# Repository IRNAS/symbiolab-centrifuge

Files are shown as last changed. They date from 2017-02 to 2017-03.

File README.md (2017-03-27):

# Symbiolab centrifuge

## Overview	
Symbiolab centrifuge is a DIY project still in development for Symbiolab at institute IRNAS. The centrifuge is based on our very own Symbiolab driver PCB on which a repository will be created in a short future. The whole centrifuge, besides the PCB, is made of cheap and easy accsesible parts, like brushless motors, and lasercut or 3D printed parts.

## Table of contents
 - [overview](#OvER)
 - [Part list](#LIST)
 - [Parts](#PARTS)
 - [Centrifuge schematic](#SCH)
 - [Centrifuge housing](#DXF)
 - [arduino code](#CODE)

## Required parts list	
 - Symbiolab driver
 - Brushless motor 
 - Electronic speed contoller "ESC"
 - IR tachometer
  * LMV 761
  * IR LED
  * IR photodiode
  * 33K resistor
  * 25 ohm resistor
 - Three state switch
 - DC-025 DC power jack connector
 - XT60 female connector
 - Electric cables and jumper wires
 - Acrylic glass "plexiglas"
 - M3 15mm nuts and bolts

## Parts	

### Symbiolab driver
Symbiolab driver is a project developed by Institute IRNAS, for DIY laboratory equipment. this is its first finished installment. Symbiolab driver is based on [NODEMCU](http://www.nodemcu.com/index_en.html) firmware, that enables future expansion to wireless controll.

### Brushless motor/ ESC
For the Symbiolab centrifuge we are using a [A2212 KV1000](http://www.robotdigg.com/product/710/A2212-brushless-drone-motor) brushless motor controlled by a [Skywalker 40A ESC controller](http://www.robotdigg.com/product/802/Skywalker-40A-ESC)

### IR tachometer
IR tachometer is used for RPM sensing and is crucial to achieving a self speed regulating controll. The sensor works with the help of reflecting light from the brushless motor therefore it is important to tape up a part of the motor, with a black(dark) tape, to create different levels of light reflecting from the motor. A LMV 761 comparator is added to transform the analog value from the photodiode to a rectangle pulse when it exceeds a reference value set via potentiometer. With this it is possible to connect the photodiode to a interrupt pin, making shure we do not miss out any positive pulses resoulting a foulty rpm reading. this method is also fater than ADC reading, thus making the whole controller faster.

#### Tachometer schematic 
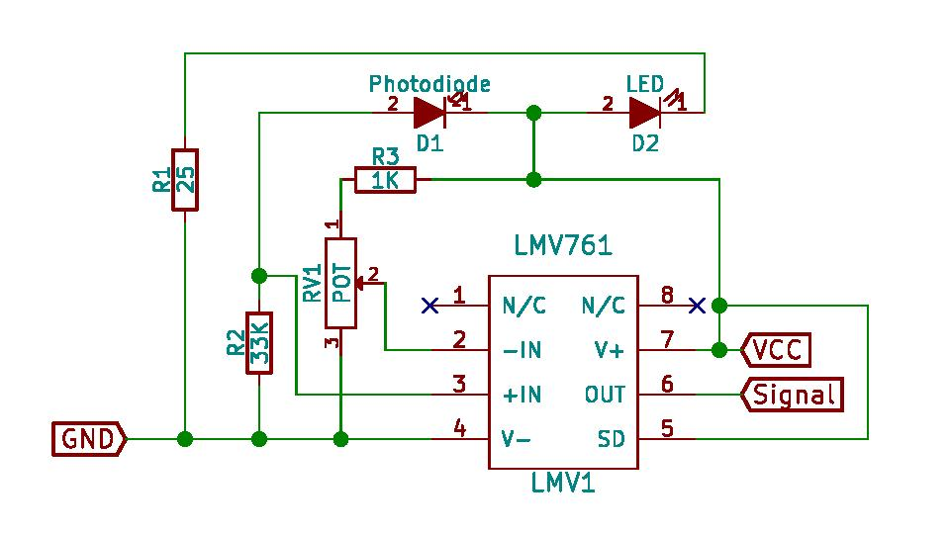
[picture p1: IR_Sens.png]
Tachometer schematic


### Three state switch
the switch is essentially used to turn on/off the centrifuge, however you can switch between power from the DC jack or LiPo battery.

## Centrifuge schematic	
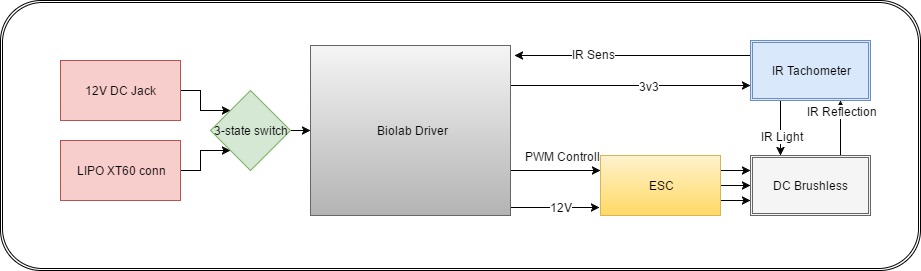
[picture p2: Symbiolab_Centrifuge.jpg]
Centrifuge schematic

To choose the power supply source, both the dc jack and XT60 are connected the 3 state switch on pins IN1 and IN2. The switch output is connected to the 12V IN terminal block on the Biolab driver. For IR tachomer we need to cennect 3v3 power suply from the Biolab driver, in return the IR tachomer sends back IR Sens data(HIGH or LOW) depending on the motor position.  The ESC is connnected to the Biolab driver via 12v power supply and the PWM GPIO.

The default pins on the Biolab drivers are:

FUNCTION|PIN NO.
--------|-------
ESC PWM | D0
IR Sens | D8

Or you could also change the pin definitions in the [Code](https://github.com/Ubercic/Symbiolab_Centrifuge/blob/ArduinoCode/ArduinoCode/CentrifugaV1RPM_No_PID/CentrifugaV1RPM_No_PID.ino)

## Centrifuge housing	
All the components for the housing are lasercut from plexiglas (approx 500mm x500mm) and screwed together with M3 15mm nuts and bolts. The DXF files can be found in the [DXF_Files](https://github.com/Ubercic/Symbiolab_Centrifuge/tree/master/DXF_Files) folder.

## Arduino code	
The code is developed in the Arduino IDE environment using [Arduino core](https://github.com/esp8266/Arduino) for use of the lua based NODEMCU with the ease of arduino coding. A working arduino code is uploaded, but it still needs some fine tuning and testing.

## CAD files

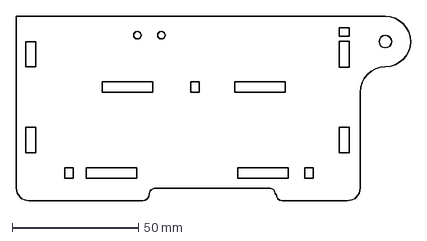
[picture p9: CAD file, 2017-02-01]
DXF_Files/BASE_RIGHT.dxf
156.0 x 73.0 mm

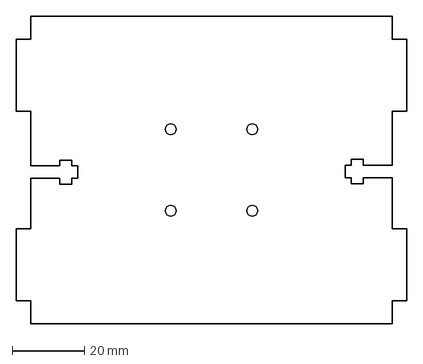
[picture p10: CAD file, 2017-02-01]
DXF_Files/MOTOR_BASE.dxf
108.0 x 85.0 mm

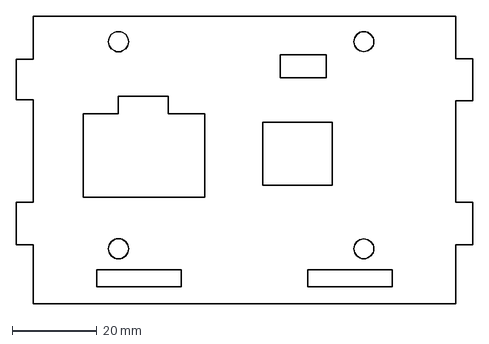
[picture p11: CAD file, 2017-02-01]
DXF_Files/BASE_FRONT.dxf
108.0 x 68.0 mm

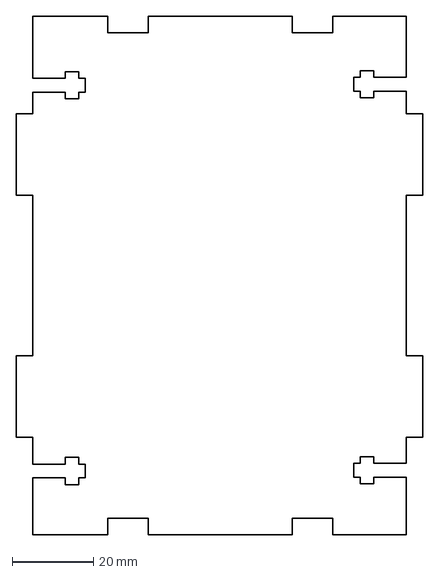
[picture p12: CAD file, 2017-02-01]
DXF_Files/COVER_TOP.dxf
100.0 x 127.6 mm

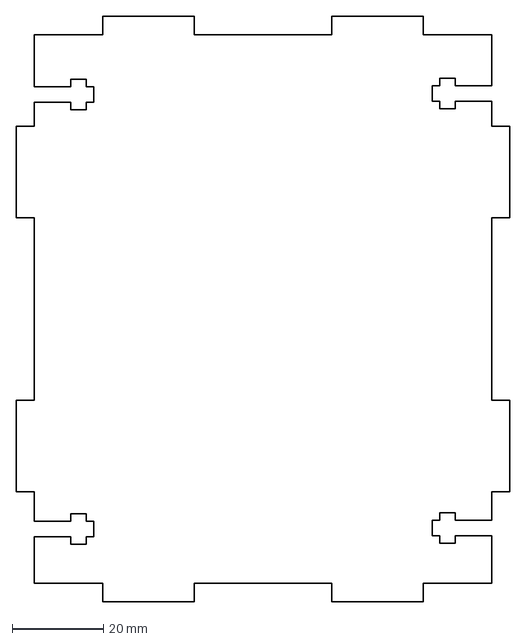
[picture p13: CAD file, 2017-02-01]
DXF_Files/BASE_BOTTOM.dxf
108.0 x 128.0 mm

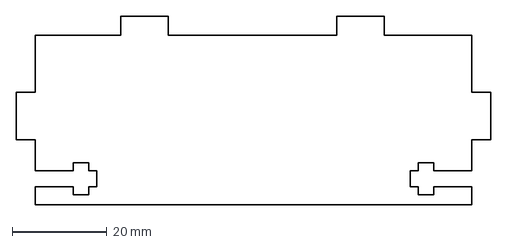
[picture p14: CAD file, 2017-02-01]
DXF_Files/COVER_BACK.dxf
100.0 x 39.8 mm

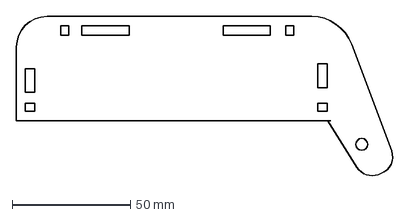
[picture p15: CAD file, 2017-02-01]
DXF_Files/COVER_LEFT.dxf
160.0 x 68.0 mm

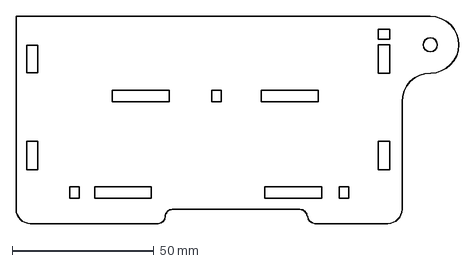
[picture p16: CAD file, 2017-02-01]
DXF_Files/BASE_LEFT.dxf
156.0 x 73.0 mm

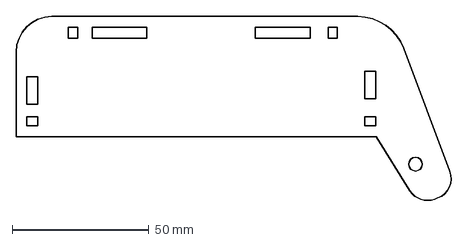
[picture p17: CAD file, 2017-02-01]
DXF_Files/COVER_RIGHT.dxf
159.3 x 68.0 mm

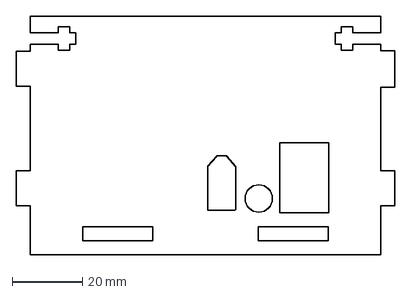
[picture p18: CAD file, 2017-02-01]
DXF_Files/BASE_BACK.dxf
108.0 x 68.0 mm

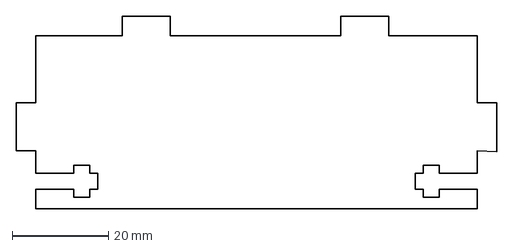
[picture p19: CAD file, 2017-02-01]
DXF_Files/COVER_FRONT.dxf
100.0 x 40.0 mm

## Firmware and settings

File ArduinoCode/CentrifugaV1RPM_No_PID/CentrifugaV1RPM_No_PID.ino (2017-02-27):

/**The MIT License (MIT)

Copyright (c) 2015 by Daniel Eichhorn

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
See more at http://blog.squix.ch
*/

#include <Wire.h>
#include <SPI.h>
#include "SSD1306.h"
#include "OLEDDisplayUi.h"
#include <Servo.h> 

SSD1306  display(0x3c, D4, D3);
OLEDDisplayUi ui     ( &display );

// how many frames are there?
int frameCount = 3,overlaysCount = 1;

Servo myservo;

/////////////////////////////////////////////////////// 
//pin definitions
int ESCpin = D0;
int Apin = D6;
int Bpin = D5;
int ENTERpin = D7;
int IRpin = D8;

////////////////////////////////////////////////////////
//ENCODER
int encDIR = 0;
int encSTATE = 0;
int encCOUNT = 0;
volatile byte A_SIG = LOW;
volatile byte B_SIG = HIGH;
volatile byte ENTER = LOW;

////////////////////////////////////////////////////////
// rpm reading 
int sensorvalue;
int state1 = HIGH;
int state2 = LOW;
float RPM = 0;
float TRPM = 0;

///////////////////////////////////////////////////////
//TIMERS
int MIN = 0;
int SEC = 1;
int ESC_PWM = 20;
unsigned long previusMillis = 0;
unsigned long previusSec = 0;
unsigned long TIME = 0;
unsigned long prevMillis = 0;
unsigned long previusPWM = 0;
unsigned long previusENTER = 0;
unsigned long previusPrint = 0;
unsigned long interval = 200;
unsigned long currentTime;
unsigned long prevTime = 0;
unsigned long diffTime = 0;

///////////////////////////////////////////////////////////////////////////////////////////////////
// interrupts for encoder reading
void A_RISE()
{
 detachInterrupt(Apin);
  A_SIG = HIGH;
  if(B_SIG == LOW) encDIR = 1;
  if(B_SIG == HIGH) encDIR = -1;
  ENC_COUNT();
 attachInterrupt(Apin, A_FALL, FALLING);
}
void A_FALL()
{
  detachInterrupt(Apin);
  A_SIG = LOW;
  if(B_SIG == HIGH) encDIR = 1;
  if(B_SIG == LOW) encDIR = -1;
  ENC_COUNT();
  attachInterrupt(Apin, A_RISE, RISING); 
}
void B_RISE()
{
  detachInterrupt(Bpin);
  B_SIG = HIGH;
  if(A_SIG == HIGH) encDIR = 1;
  if(A_SIG == LOW) encDIR = -1;
  ENC_COUNT();
  attachInterrupt(Bpin, B_FALL, FALLING);
}
void B_FALL()
{
  detachInterrupt(Bpin);
  B_SIG = LOW;
  if(A_SIG == LOW) encDIR = 1;
  if(A_SIG == HIGH) encDIR = -1;
  ENC_COUNT();
  attachInterrupt(Bpin, B_RISE, RISING); 
}
///////////////////////////////////////////////////////////////////////////////////////////////////
// interrupts for RPM Sens
void IR_RISE()
{
 detachInterrupt(IRpin);
 state1 = HIGH;
 RPM_Calculator();
 attachInterrupt(IRpin, IR_FALL, FALLING);
}
void IR_FALL()
{
  detachInterrupt(IRpin);
  state1 = LOW;
  RPM_Calculator(); 
  attachInterrupt(IRpin, IR_RISE, RISING); 
}

//////////////////////////////////////////////////////////////////////////////////////////////////
// definiton of frames
void msOverlay(OLEDDisplay *display, OLEDDisplayUiState* state) 
{
  display->setTextAlignment(TEXT_ALIGN_RIGHT);
  display->setFont(ArialMT_Plain_10);
  display->drawString(128, 0, String(millis()));
}

void drawTIME(OLEDDisplay *display, OLEDDisplayUiState* state, int16_t x, int16_t y) 
{
  //basic menu for setting time
  display->setTextAlignment(TEXT_ALIGN_CENTER);
  display->setFont(ArialMT_Plain_16);
  display->drawString(64 , 0 , "SET TIME");
  //display->setTextAlignment(TEXT_ALIGN_LEFT);
  //display->setFont(ArialMT_Plain_10);
  //display->drawString(0 , 20 , "SET TIME");
  display->setFont(ArialMT_Plain_24);
  display->setTextAlignment(TEXT_ALIGN_CENTER);
  String Time = String(MIN) + ":" + String(SEC);
  display->drawString(64 , 28 , Time);
  display->setFont(ArialMT_Plain_10);
  display->setTextAlignment(TEXT_ALIGN_LEFT);
  display->drawString(0 , 52 , "PLUS");
  display->setTextAlignment(TEXT_ALIGN_CENTER);
  display->drawString(64 , 52 , "MINUS");
  display->setTextAlignment(TEXT_ALIGN_RIGHT);
  display->drawString(128 , 52 , "OK");
}

void drawSPEED(OLEDDisplay *display, OLEDDisplayUiState* state, int16_t x, int16_t y) 
{
  // Display to set Rpm
  display->setTextAlignment(TEXT_ALIGN_CENTER);
  display->setFont(ArialMT_Plain_16);
  display->drawString(64 , 0 , "SET SPEED");
  //display->setTextAlignment(TEXT_ALIGN_LEFT);
  //display->setFont(ArialMT_Plain_10);
  //display->drawString(0 , 20 , "SET SPEED");
  display->setFont(ArialMT_Plain_24);
  display->setTextAlignment(TEXT_ALIGN_CENTER);
  String Rpm = String(ESC_PWM);
  display->drawString(64 , 28 , Rpm);
  display->setFont(ArialMT_Plain_10);
  display->setTextAlignment(TEXT_ALIGN_LEFT);
  display->drawString(0 , 52 , "PLUS");
  display->setTextAlignment(TEXT_ALIGN_CENTER);
  display->drawString(64 , 52 , "MINUS");
  display->setTextAlignment(TEXT_ALIGN_RIGHT);
  display->drawString(128 , 52 , "OK");
}

void drawWORK(OLEDDisplay *display, OLEDDisplayUiState* state, int16_t x, int16_t y) 
{

  display->setTextAlignment(TEXT_ALIGN_CENTER);
  display->setFont(ArialMT_Plain_16);
  display->drawString(64 , 0 , "WORKING");
  display->setTextAlignment(TEXT_ALIGN_LEFT);
  display->setFont(ArialMT_Plain_10);
  String RPm = String(RPM) + " rpm";
  display->drawString(0 , 20 , RPm);
  display->setFont(ArialMT_Plain_24);
  display->setTextAlignment(TEXT_ALIGN_CENTER);
  String Time = String(MIN) + ":" + String(SEC);
  display->drawString(64 , 28 , Time);
  display->setFont(ArialMT_Plain_10);
  display->setTextAlignment(TEXT_ALIGN_LEFT);
  if(state1 == HIGH) display->drawString(0 , 52 , "L");
  else display->drawString(0 , 52 , "H");
  String Sens = String(sensorvalue);
  display->setTextAlignment(TEXT_ALIGN_CENTER);
  display->drawString(64 , 52 , Sens);
  String Esc = String(ESC_PWM);
  display->setTextAlignment(TEXT_ALIGN_RIGHT);
  display->drawString(128 , 52 , Esc);
}

void drawFrame4(OLEDDisplay *display, OLEDDisplayUiState* state, int16_t x, int16_t y) 
{
   
}

void (*frames[])(OLEDDisplay *display, OLEDDisplayUiState* state, int16_t x, int16_t y) = { drawTIME, drawSPEED, drawWORK, drawFrame4 }; 
void (*overlays[])(OLEDDisplay *display, OLEDDisplayUiState* state)             = { msOverlay };

///////////////////////////////////////////////////////////////////////////////////////////////////


void setup()   
{  

  Serial.begin(115200);
  pinMode(Apin, INPUT_PULLUP);
  pinMode(Bpin, INPUT_PULLUP);
  pinMode(ENTERpin, INPUT_PULLUP);
  myservo.attach(ESCpin);
 
//////////////////////////////////////////////
//display setup

  ui.setTargetFPS(10);
  ui.disableAutoTransition();
  ui.disableIndicator();
  ui.setIndicatorPosition(RIGHT);            // You can change this to TOP, LEFT, BOTTOM, RIGHT
  ui.setIndicatorDirection(LEFT_RIGHT);       // Defines where the first frame is located in the bar.
  ui.setFrameAnimation(SLIDE_LEFT);           // You can change the transition that is used SLIDE_LEFT, SLIDE_RIGHT, SLIDE_TOP, SLIDE_DOWN
  ui.setFrames(frames, frameCount);           // Add frames
  ui.setOverlays(overlays, overlaysCount);    // Add overlays
  ui.init();
  display.flipScreenVertically();
  
///////////////////////////////////////////////
 //digitalWrite(IR_LEDpin, HIGH);
 
 interrupts();
 attachInterrupt(Apin, A_RISE, RISING);
 attachInterrupt(Bpin, B_RISE, RISING);
 attachInterrupt(IRpin, IR_RISE, RISING);
 
////////////////////////////////////////////////
// Esc Calibration 
  //CalibrateESC();              // run if the esc needs calibration
  myservo.write(ESC_PWM);
}

///////////////////////////////////////////////////////////////////////////////////////////////


void loop() 
{
  int remainingTimeBudget = ui.update();         // display refresh
  unsigned long currentMillis = millis();        //countdown timer
  if (currentMillis - previusPrint >= 1000)      // Serial print of current speed
  {
      
      Serial.print(RPM,0);
      Serial.print("/");
      Serial.println(ESC_PWM);
      previusPrint = currentMillis;
  }
  if (currentMillis - previusSec >= 1000)
  {
    previusSec = currentMillis;
    SEC = SEC - 1;
    if(SEC<=0)                              
      {
        if(SEC<=0 && MIN<=0)                    //runs on first round if SEC and MIN set to 0
         {
            while(ESC_PWM > 20){                // deceleration when time hits 0:0
              ESC_PWM = ESC_PWM - 5;
              myservo.write(ESC_PWM);
            }
              ESC_PWM = 20;
              SetTIME();
              SetSPEED();
         }
         else
         {
            MIN = MIN - 1;
            SEC = SEC + 59;
         }
      }
   }
  
  if(ENTER == LOW) {
    while(ESC_PWM > 20){                          // deceleration if canceled via encoder click
        ESC_PWM = ESC_PWM - 5;
        myservo.write(ESC_PWM);
        delay(10);
      }
    ESC_PWM = 20;
    myservo.write(ESC_PWM);
    ENTER = HIGH;
    SetTIME();                                     // stops and returns to Set time menu
    SetSPEED();
  }

  if(ESC_PWM >= 20 && ESC_PWM <= 255){           // changing speed while running
    if(encSTATE!=0){                          
       ESC_PWM = ESC_PWM + 1*encSTATE;
       encSTATE = 0;
                          //range limiting
       if(ESC_PWM <= 20){
         ESC_PWM = 20;
        }
       else if(ESC_PWM >= 255){
          ESC_PWM = 255;
       }
       Serial.print("Write ESC: ");
       Serial.println(ESC_PWM,DEC);
       myservo.write(ESC_PWM);
     }  
   }
   
  ReadEnter();
  //SetESC();  
}

///////////////////////////////////////////////////////////////////////////////////////////////////////
// Setting up RPM

void SetSPEED()
{
  ENTER = HIGH;
  ui.ThisFrame(3);
  
   while(ENTER == HIGH)                                         //runs till confirm with enter.
    {
    if(ESC_PWM >= 20 && ESC_PWM <= 255){                           
        ESC_PWM = ESC_PWM + 1*encSTATE;
                          //Range limiting
        if(ESC_PWM <= 20)
        {
          ESC_PWM = 20;
        }
        if(ESC_PWM >= 255)
        {
          ESC_PWM = 255;
        }
        encSTATE = 0;  
      }

      int remainingTimeBudget = ui.update();
      if (remainingTimeBudget > 0) {
      delay(remainingTimeBudget);  
      } 
      ReadEnter();                        
    }
    ENTER = HIGH;
    ui.ThisFrame(1);
}

///////////////////////////////////////////////////////////////////////////////////////////////////////
// Setting up Time

void SetTIME()
{
 ui.ThisFrame(2);
  
  ENTER = HIGH;
  while(ENTER == HIGH)                                        //set minutes
    {
      MIN = MIN + encSTATE;
      encSTATE = 0;
      if(MIN <= 0)MIN = 0;
      int remainingTimeBudget = ui.update();
      if (remainingTimeBudget > 0) {
      delay(remainingTimeBudget);
      }
      ReadEnter();
    }
 
  ENTER = HIGH;
  while(ENTER == HIGH)                                        //set seconds
   {
      SEC = SEC + encSTATE;
      encSTATE = 0;
      if(SEC < 0 && MIN > 0){
        SEC = 59;
        MIN = MIN - 1;
      }
      if(SEC > 59){
        SEC = 0;
        MIN = MIN + 1; 
      }
      int remainingTimeBudget = ui.update();
      if (remainingTimeBudget > 0) {
      delay(remainingTimeBudget);
      }
      ReadEnter();   
   }              
}
////////////////////////////////////////////////////////////////////////////////////////////////////////
//encoder click debounce
void ReadEnter()
{
  bool Enter = digitalRead(ENTERpin);                      // Enter debounce
  if(Enter == LOW){
    unsigned long currentmillis = millis();
    if (currentmillis - previusENTER >= 500)
    {
     ENTER = Enter;
     previusENTER = currentmillis;
    }
  }
}
///////////////////////////////////////////////////////////////////////////////////////////////////////
// Improvised avto speed correction, copares current rpm target rpm and scales PWM on esc accordingly
 
void SetESC()                                             
{
  unsigned long currentmillis = millis();
  if (currentmillis - previusPWM >= 500)
  {
  float diffRPM = RPM - TRPM;
  if(diffRPM > 200) ESC_PWM--;
  if(ESC_PWM >= 255) ESC_PWM = 255;
  if(diffRPM < -200) ESC_PWM++;
  if(ESC_PWM <= 20) ESC_PWM = 20;
  if(TRPM <= 3000) ESC_PWM = 20;
  if(diffRPM > 2000) ESC_PWM = 20;  // it current rpm is greatly bigger than target rpm set throttle to zero
  previusPWM = currentmillis;
  myservo.write(ESC_PWM);
  }
}

////////////////////////////////////////////////////////////////////////////////////////////////////////
// encoder pulse counter. to counter jumping values in case of missing a encoder pulse.
void ENC_COUNT()
{
  encCOUNT = encCOUNT + encDIR;
  if(encCOUNT <= -4)
  {
    encSTATE = -1;
    encCOUNT = 0;
  }
  else if(encCOUNT >= 4)
  {
    encSTATE = 1;
    encCOUNT = 0;
  }
  encDIR = 0;
}
////////////////////////////////////////////////////////////////////////////////////////////////////////
// RPM Calculator
void RPM_Calculator(){    
  
 if(state2!=state1){                           //counts when the state change, thats from (dark to light) or                                                 //from (light to dark)
    if (state2>state1){                         // only every second change
      currentTime = micros();                   // Get the arduino time in microseconds
      diffTime = currentTime - prevTime;        // calculate the time diff from the last meet-up
      RPM = 60000000/diffTime;                  // calculate how many rev per minute
      prevTime = currentTime;
    }
    state2 = state1;
  }
}
////////////////////////////////////////////////////////////////////////////////////////////////////////
//ESC calibration
void CalibrateESC(){
  ESC_PWM = 255;
  myservo.write(ESC_PWM);
  delay(3000);
  ESC_PWM = 20;
  myservo.write(ESC_PWM);
}

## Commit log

2017-02-01 Added first arduino code and OLED Library
    The arduino code is not finished and works conditionaly.
    Oled library is edited and added to the code
2017-02-01 Added centrifuge DXF files
    still need to make the cover a bit higher to fit in the rotator.
    [BASE_BACK.dxf, BASE_BOTTOM.dxf, BASE_FRONT.dxf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]
2017-02-01 Changed the speed control from avto rpm correction, to manual ESC PWM setting.
    [CentrifugaV1RPM_No_PID.ino]
2017-02-03 Code fixes.
    fixed encoder jumping
    a serius error occurs randomy where node mcu writes a high value on ESC
    PWM for no apparent reason. Could not replicate the bug.
    [CentrifugaV1RPM_No_PID.ino]
2017-02-13 RPM Interrupt
    Swiched from analog read to Interrupt rutine to be sure not to miss any
    pulses thus more accurate RPM sensing. Still no avto correction tho.
    [CentrifugaV1RPM_No_PID.ino]
2017-03-27 Added IR Sens schematic
